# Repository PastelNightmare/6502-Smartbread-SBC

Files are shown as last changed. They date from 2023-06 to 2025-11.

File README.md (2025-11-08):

# Archiving, for now! I don't recommend using V1 of the board as of now.
As I play around with the finished PCB, I realized there are a few issues with it. 
- A13 is not connected to the RAM chip, so you have to make a jumper to it from elsewhere. 
- The below mentioned difference in clock generation from other processors to the WDC version.
- I'm using the WDC 65C22S, which does NOT have an open-drain interrupt output! It has a totem pole ouput! Right now, it's currently wired as if it were open drain, which is fine as long as you **don't use interrupts.** If you do though, you will short circuit the IRQ lines of the VIA.

# Upcoming hardware changes? 
- Reconnect A13, obviously.
- Make the system clock with WDC parts in mind
- Add schottky diodes on the VIA interrupts to connect them with the other open drain interrupts. Fine at 2mhz clock speed.
- Change address decoding to use Daryl Rictors DEC-1. https://sbc.rictor.org/decoder.html

# Upcoming software changes? 
- A customized version of EHBasic, which I've already made. Includes commands for sound, clearing screen, and returning to the monitor.
- Updating VGM player to load VGM out of RAM instead of ROM, and commented to explain better what it is doing. 
- Porting WozMon to this board for easier data entry. DeMon is fine, but it was more a project for me anyway. 
- A better terminal emulator program
- Eventually, using the new interrupts to allow streaming of VGM from the serial port. But that is a long time off. 

# IMPORTANT DESIGN NOTE
Due to a design difference with the WDC version of the 65C02 processor, this board will not work with WDC chips without a small modification. See "Using a WDC 65C02" below.

# SmartBread: A 6502 based single-board computer 
Its name came from a friend who called it this when they saw my initial prototypes on a breadboard. MintSpark Electronics was the working "maker name" for my projects, though it may not be for long. Other than another 6502 based single board computer, of which many exist, this was many firsts for me. Starting in 2017, I had a goal to build a 6502 system on a breadboard. As it grew, it became my first real endeavour into 6502 assembly, coding for an actual system, trying to make user friendly software, and PCB making. I now have working PCBs, a few programs, and much more work to do. 

Repo includes software, PCB gerber files and resources. ROM included has DeMon 4.0 and EhBASIC w/ its cold start monitor. Other files can be added and recompiled as desired 

Software assumes you are using the Kowalski 6502 simulator for assmebly. https://sbc.rictor.org/kowalski.html 

# Disclaimer: 
This was my first stab at assembly of any kind. While the code does exactly what I want it to do for this system, I understand that my code is not pretty by any stretch, and there is tons of room for improvement. I'm a novice, so please go easy on me. Some things like address decoding were figured out with the help of the 6502 forum and the 6502 Primer by Garth Wilson. Found at: http://wilsonminesco.com/

# Specs
- 65C02 processor running at 2mhz
- 2x 65C22 VIA (versatile interface adapter) chips
- 1x 65C51 ACIA (UART) chip
- SN76489 soundchip
- 32KB EEPROM (AT28C256)
- 16KB RAM (Alliance AS6C62256. 32kb chip, address decoding makes it 16kb)
- ATTINY26 for keyboard input
- Quad NAND gate 74 chip for address decoding
- Jumpers to fully configure serial port settings
- GPIO port, spare 8 bit parallel. 5v and GND also available. 
- PS2 keyboard input
- RCA output for sound. 
- Displays to charcter LCD or serial using any terminal device (board has a slot for the BatSocks tellymate tiny for this purpose http://www.batsocks.co.uk/products/Other/TellyMate%20Tiny.htm)

# Parts list
- R1-R6: 3.3k through hole resistor
- R7, R8: 10k through hole resistor
- R9: 370 ohm resistor. 
- C1: 1uf electrolytic capacitor. 
- All other capacitors: 100nf filter. Ceramic disc.
- 6502CLCK: ECS-100AX-018 oscillator, 2MHz
- SNCLCK: ECS-100AX-018 oscillator, 4MHz
- SERCLCK: ECS-100AX-018 oscillator, 1.8432MHz
- 65C02 processor
- VIA1, VIA2: 65C22 VIA chips (keyboard doesn't work right with non-CMOS versions)
- ACIA: 65C51 ACIA chip
- ROM: AT28C256
- RAM: Alliance AS6C62256
- ADDR: CD74HCT132E
- SN: Texas Instruments: SN76489
- ATTINY26: Atmel ATTINY26
- POWER: 5v through header, or surface mount USB Mini B jack. 

# Included Software
## DeMon 4.0
DeMon (DEvice MONitor) 4.0 is a basic memory monitor for the system. You can read the memory map, write to the memory map, run code, send commands directly to the sound chip, and much more. 
### Commands
All commands are processed by pressing enter. Accepts input from onboard PS2 keyboard or ACIA (with FTDI breakout)

| Command | Example | Description | 
| --- | --- | --- |
| Read  | 4000  | Displays data at address 0x4000  |
| List |L 2000.20FF| Will display all data between addresses 0x2000 and 0x20FF |
| Write  | W 2000 FF | Writes 0xFF at address 0x2000  |
| Write next | 00 | Data byte preceded with a space will write data to next location. MUST USE WRITE COMMAND FIRST |
| Run | R 2000 | Runs code starting at address 2000 | 
| Clear | CL | Clears all displays |
| Sound | S FF | Sends 0xFF to sound chip and makes the chip process it | 

## VGM player
A simple VGM player to play VGM files for the SN76489 sound chip. Expects raw VGM hex at 8900 (0900 if you're burning to ROM). Could easily be changed to load hex out of RAM instead with one line of code. 

## Enhanced 6502 BASIC 2.22 (EhBASIC) port
Made by Lee Davison, information: http://retro.hansotten.nl/6502-sbc/lee-davison-web-site/enhanced-6502-basic/. Ported to SmartBread by me. **COMPILING NOTE:** in order to compile EhBASIC, point the include line at the beginning of the Minimal Monitor to where you've downloaded EHBASIC.ASM. Minimal monitor starts at A000 and should be used to cold start BASIC! 

# Port Description
- GPIO - 8 bit parallel GPIO port. Can attach LCD to this port to work natively with DeMon, but it isn't required and can be used for whatever else the end user desires. The current board DOES NOT have the LCD enable line on this port, but it will be added to a future revision. 
- TM - Tellymate Tiny can be connected here for composite display. The part is discontinued, but eagle files and firmware exist on the Batsocks website. 
- Serial - Gives control lines for the ACIA ports, along with GNDs next to each one. Allows these status lines to be jumpered to ground, which **should** be done for most operations. (DTR, RTS, CTS, DCD) Also provides 5v and GND for user. Can connect to a TTL to RS232 converter for any type of serial display. 
- CLKMODE - Shorting these two pins with solder or a jumper allows the serial clock to also run the processor clock. This saves one part, but makes the CPU run slightly slower. 

# Using a WDC 65C02
In order to use a WDC version of the processor in the current revision, there is a slight modification to the board that must be made. Pin 39 (PHI2O) on the chip must be lifted out of the socket or removed. Then on the underside of the board, you must bridge a connection between Pin 39 and Pin 37 of the CPU socket. 

Traditionally, you provide the clock frequency to the CPU via PHI0/PHI2 input, then drive the rest of peripherals from PHI2O output from the CPU. The board was made with this in mind. WDC chips, however, do not test or guarantee the usability of the PHI2O output. They recommend that everything onboard receives its clock from the main oscillator driving the CPU. By bridging these two points on the board and lifting pin 39 from the chip, you are routing the clock in this manner. Future board revisions will have this as a jumper to ensure compatiblity. 

# To-do list / Wishlist 
- Update display to a new, non-discontinued solution. For now, Tellymate Tiny could be used, or provided serial pins can be attached to any device with a TTL to RS232 converter (Max232 and the like): Breakout USB boards, Converted RS232 port to a real glass terminal, etc. 
- Improve code by removing useless structures / subroutines
- Adding a binary load command to DeMon load binary data directly into memory from serial port. 
- Either standalone or built-in assembly evnironment for DeMon. 
- Text editor prorgram
- SPI protocol for various peripherals. 
- Cassette interface. 
- Rewrite my old code. The VGM player is old and hard to read. This was before I knew much about anything coding wise. 
- Write a terminal emulator program. I did make SimTerm originally, but it is hot garbage.

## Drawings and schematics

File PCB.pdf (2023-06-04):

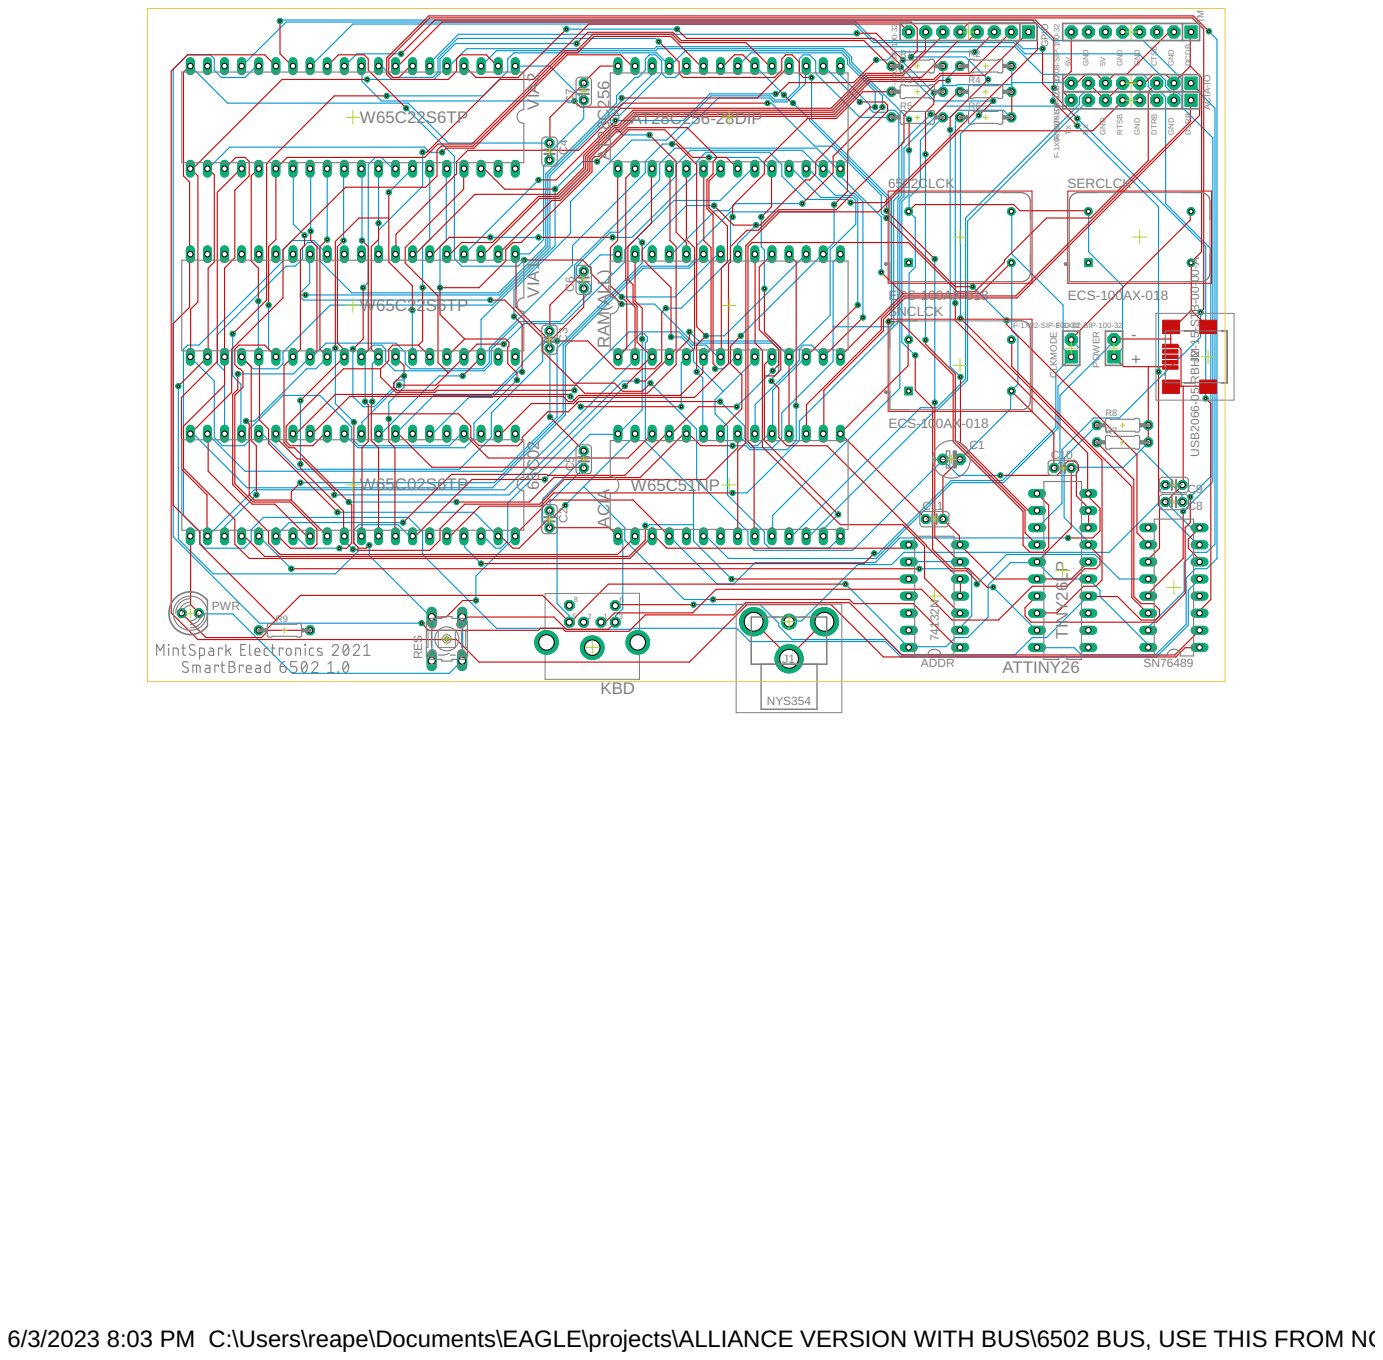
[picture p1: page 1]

6/3/2023 8:03 PM C:\Users\reape\Documents\EAGLE\projects\ALLIANCE VERSION WITH BUS\6502 BUS, USE THIS FROM NOW ON\6502 bus version\untitled.brd

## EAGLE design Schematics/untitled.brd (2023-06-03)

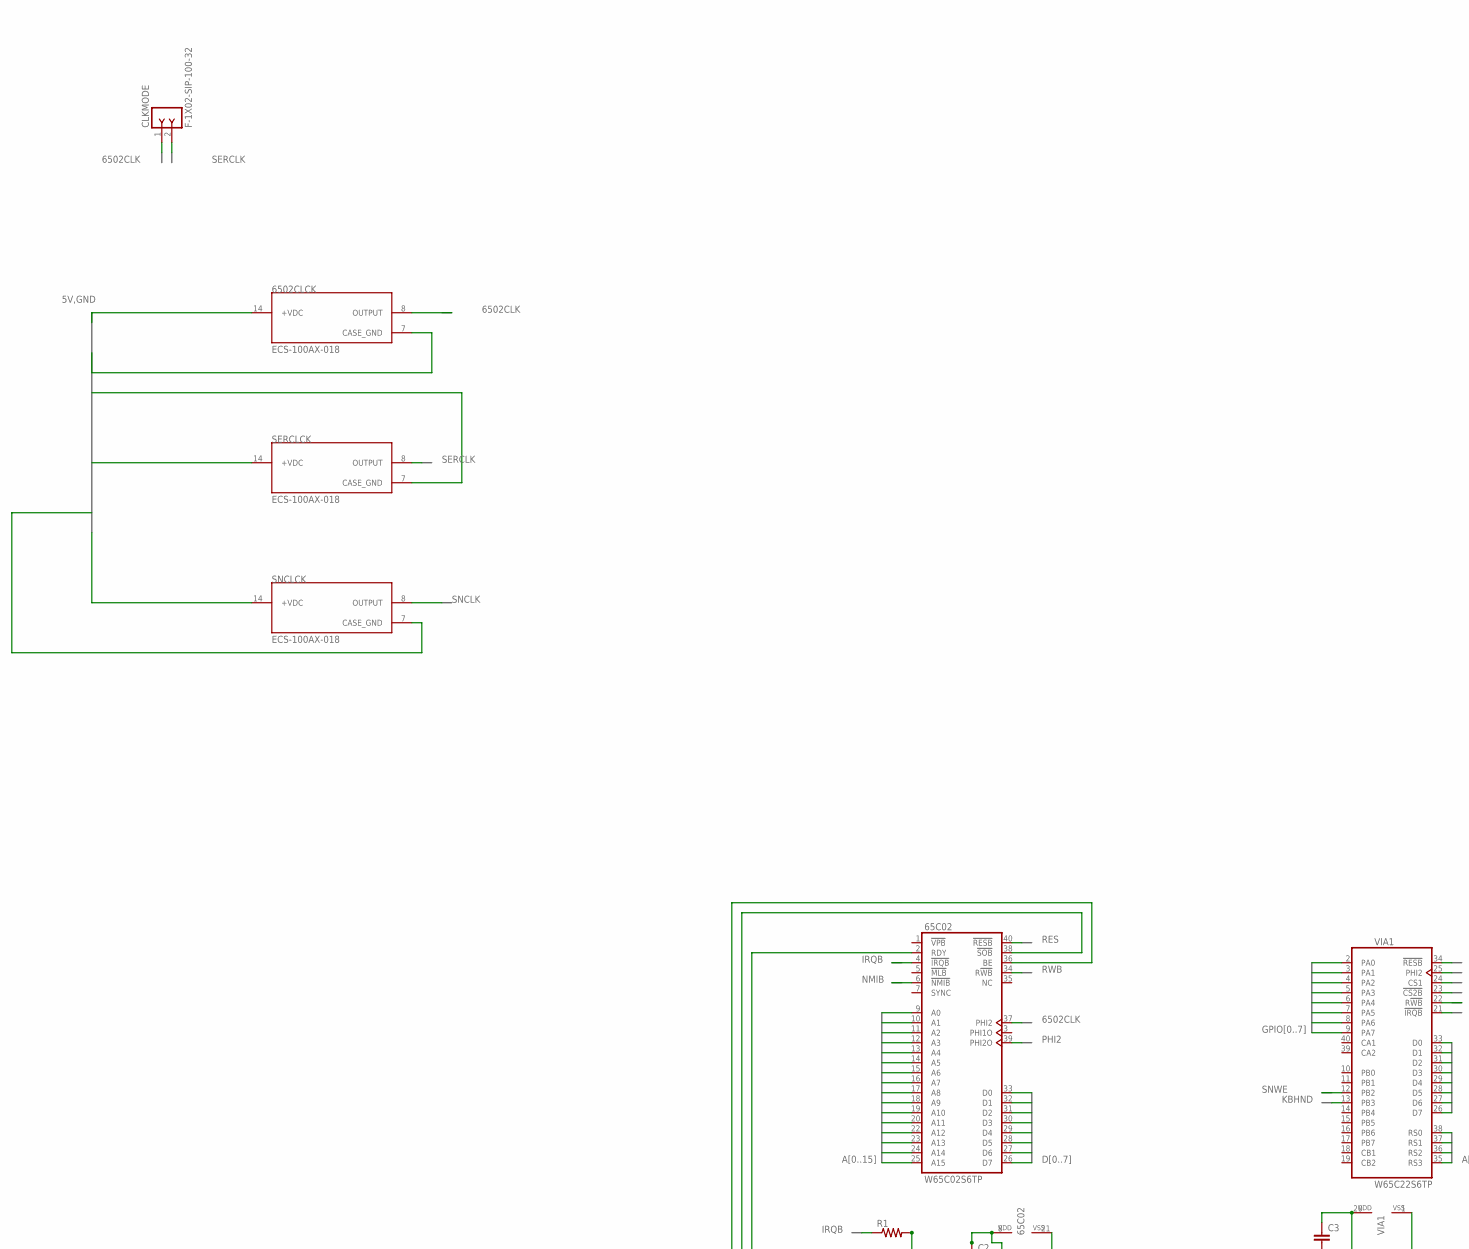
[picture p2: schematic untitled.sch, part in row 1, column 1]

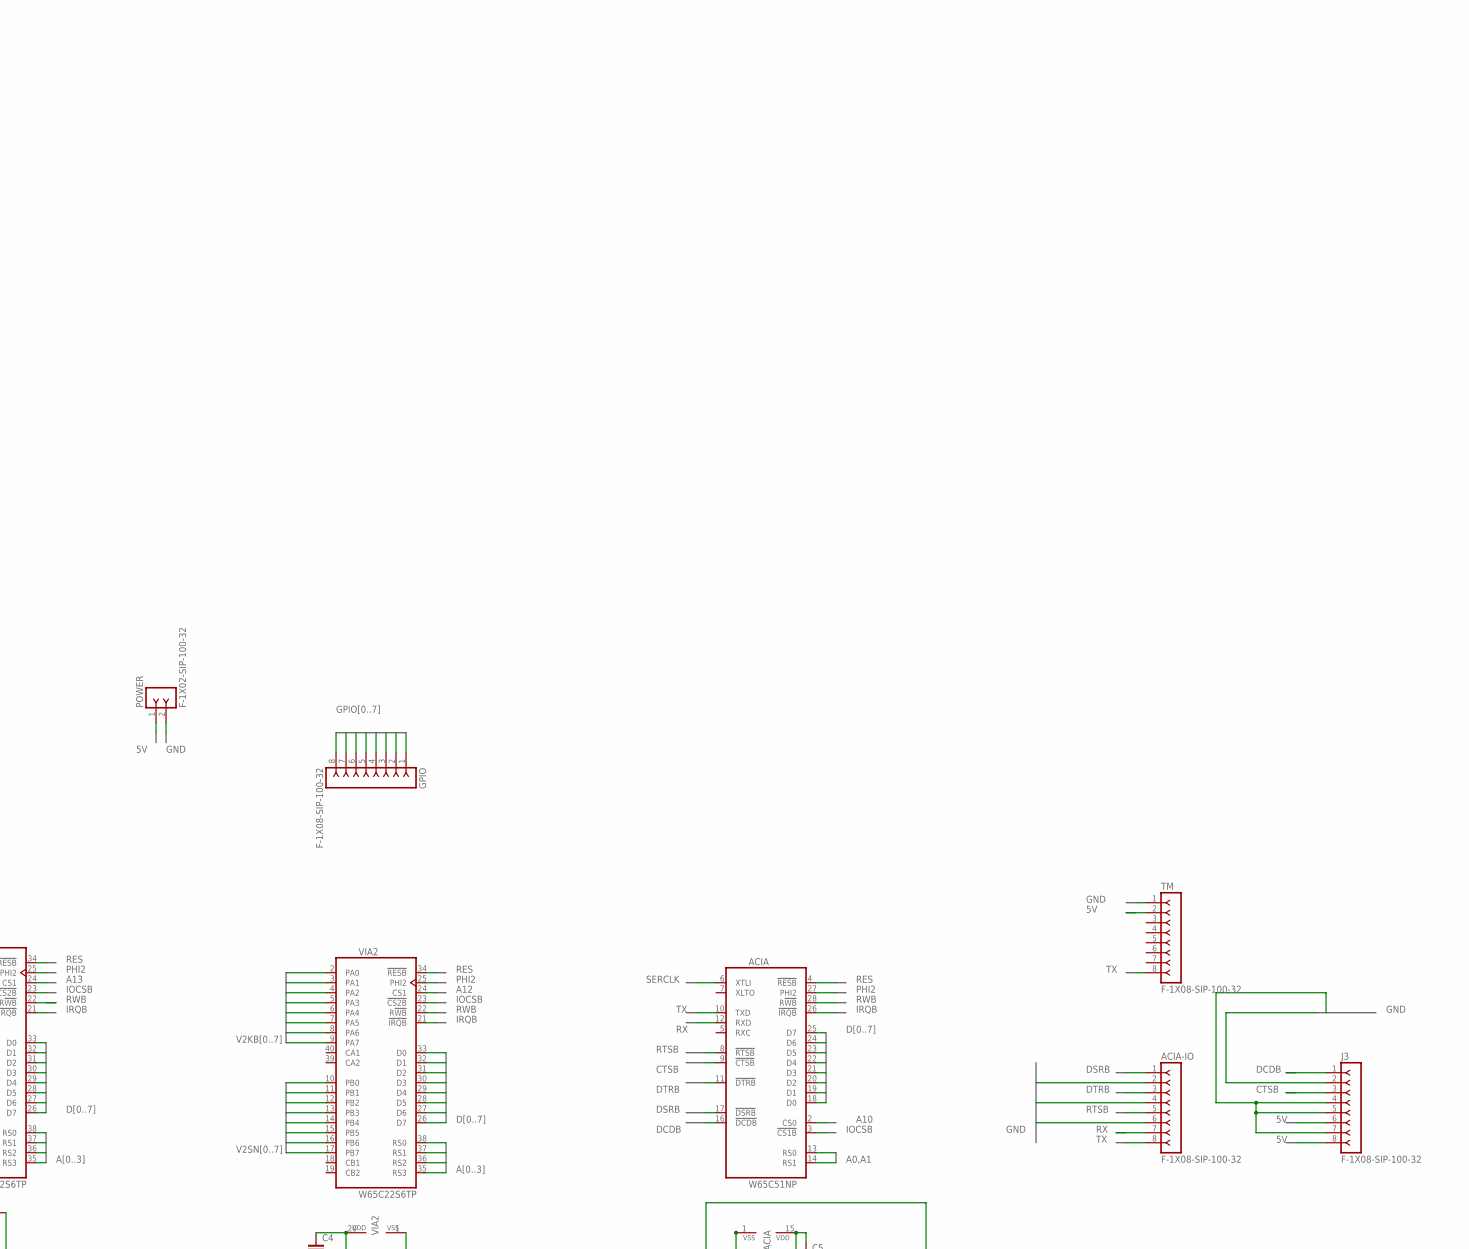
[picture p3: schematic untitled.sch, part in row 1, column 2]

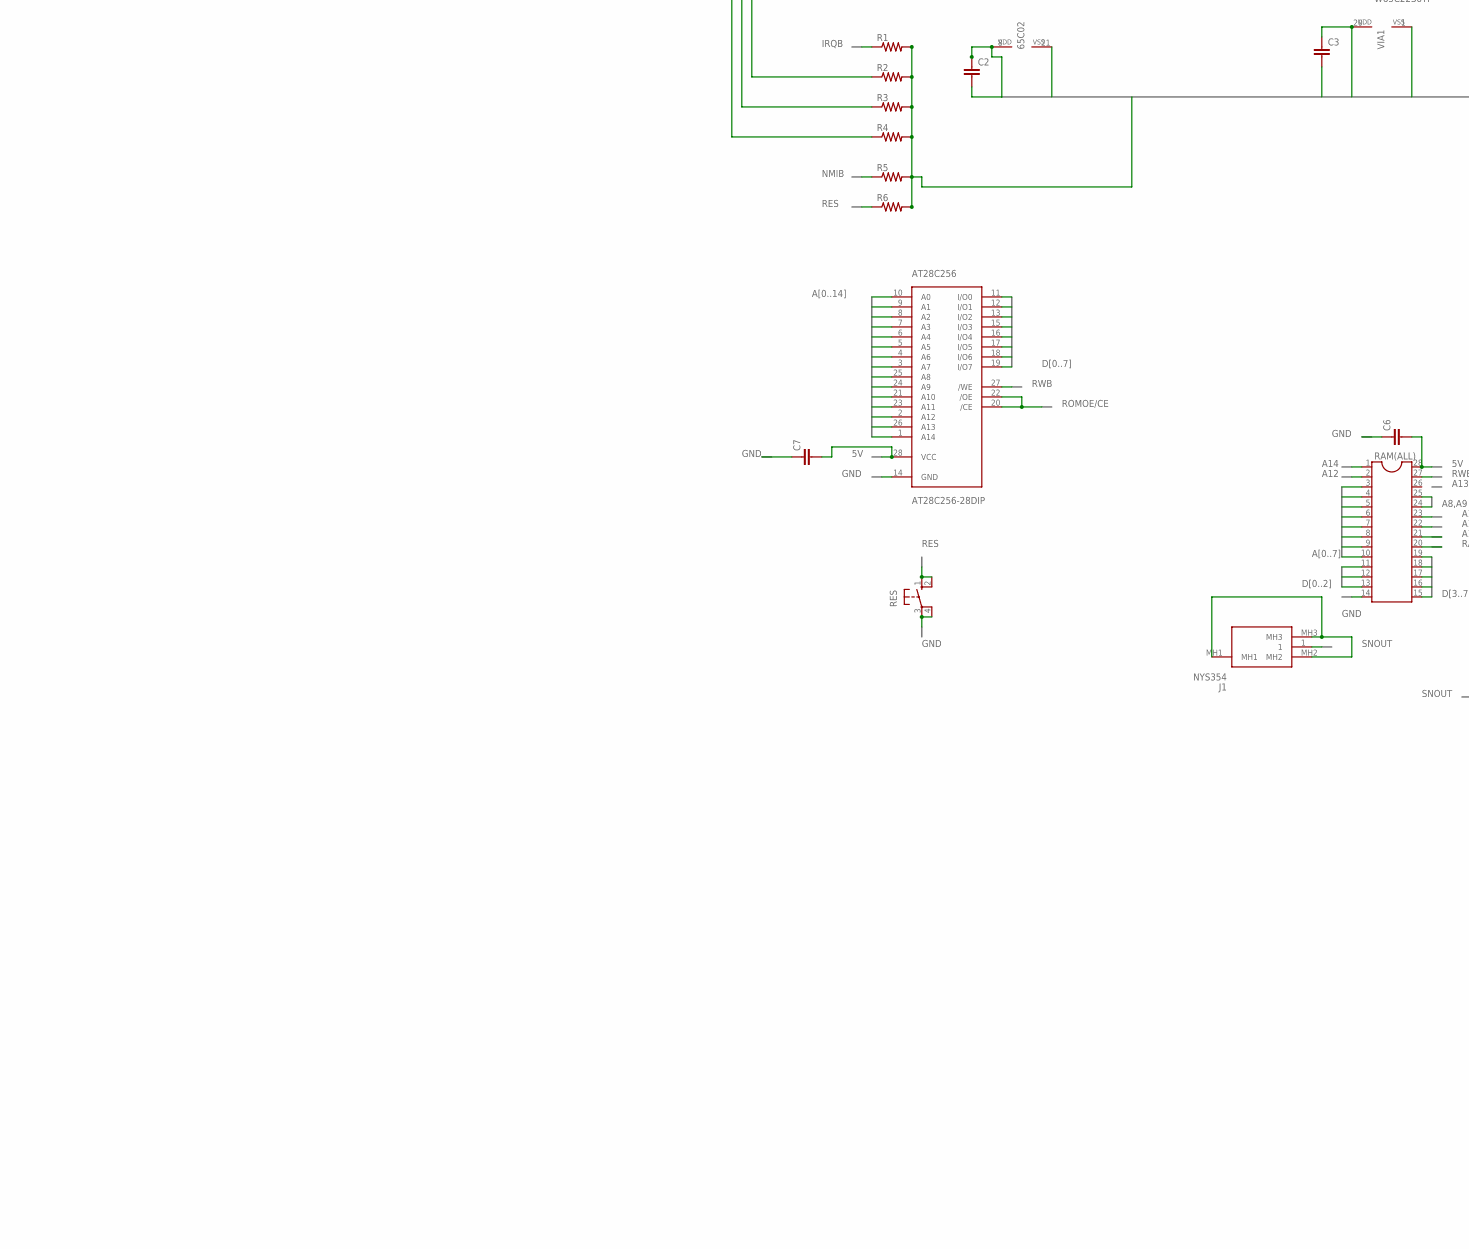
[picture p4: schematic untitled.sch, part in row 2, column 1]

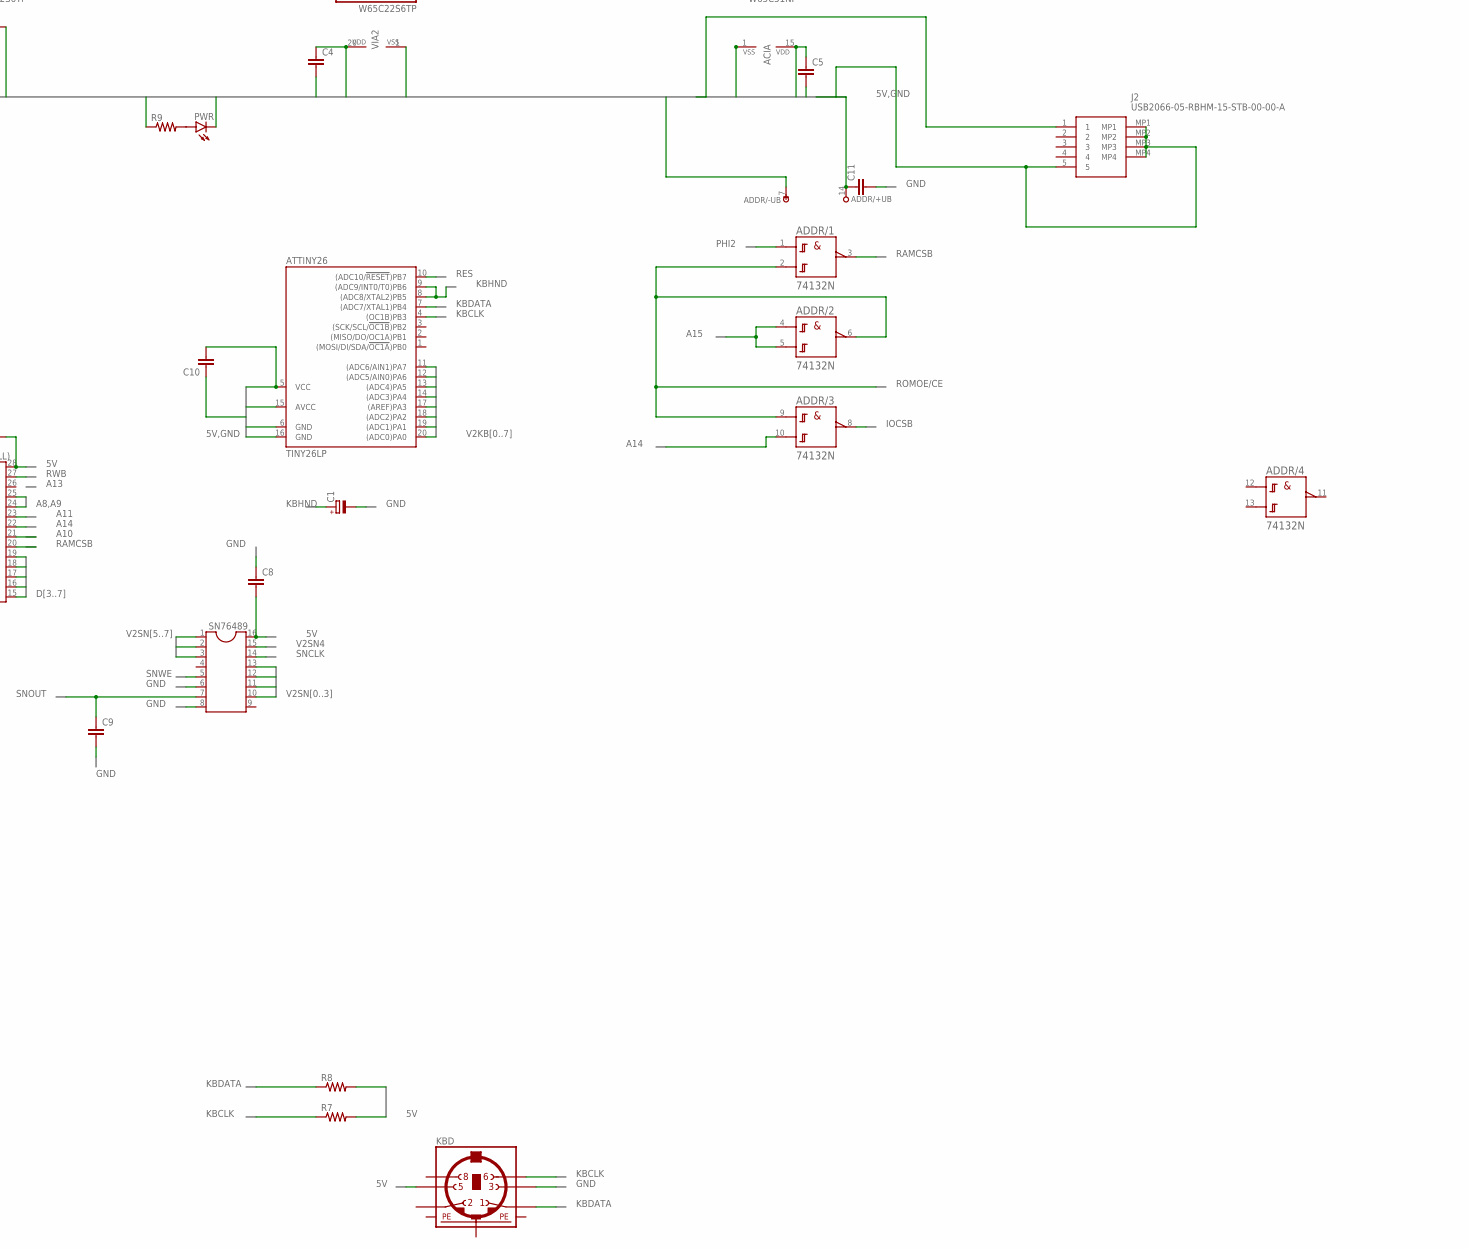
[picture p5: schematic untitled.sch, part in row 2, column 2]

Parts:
65C02: W65C02S6TP; DIL40
6502CLCK: ECS-100AX-018; OSC_ECS-100AX-018
ACIA: W65C51NP; DIL28-6
ACIA-IO: F-1X08-SIP-100-32; SIP-100-08-32
ADDR: 74132N; DIL14
AT28C256: AT28C256-28DIP; DIL28-6
ATTINY26: TINY26LP; DIL20
C1: CPOL-EUE2,5-6E; E2,5-6E
C2, C3, C4, C5, C6, C7, C8, C9, C10, C11: C-EU025-024X044; C025-024X044
CLKMODE: F-1X02-SIP-100-32; SIP-100-02-32
GPIO: F-1X08-SIP-100-32; SIP-100-08-32
J1: NYS354
J2: USB2066-05-RBHM-15-STB-00-00-A; USB206605RBHM15STB0000A
J3: F-1X08-SIP-100-32; SIP-100-08-32
KBD: MINI_DIN_6; M_DIN6
POWER: F-1X02-SIP-100-32; SIP-100-02-32
PWR: LED5MM
R1, R2, R3, R4, R5, R6, R7, R8, R9: R-US_0204/7; 0204/7
RAM(ALL): DIL28; DIL28-6
RES: 10-XX; B3F-10XX
SERCLCK: ECS-100AX-018; OSC_ECS-100AX-018
SN76489: DIL16
SNCLCK: ECS-100AX-018; OSC_ECS-100AX-018
TM: F-1X08-SIP-100-32; SIP-100-08-32
VIA1, VIA2: W65C22S6TP; DIL40

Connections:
5V: 65C02.8 (VDD), 6502CLCK.14 (+VDC), ACIA.15 (VDD), ADDR.14 (+UB), AT28C256.28 (VCC), ATTINY26.5 (VCC), ATTINY26.15 (AVCC), C2.1, C3.1, C4.1, C5.1, C6.2, C7.2, C8.2, C10.2, C11.1, J2.1, J3.6, J3.8, KBD.5, POWER.1, R1.2, R2.2, R3.2, R4.2, R5.2, R6.2, R7.2, R8.2, R9.1, RAM(ALL).28, SERCLCK.14 (+VDC), SN76489.16, SNCLCK.14 (+VDC), TM.2, VIA1.20 (VDD), VIA2.20 (VDD)
6502CLK: 65C02.37 (PHI2), 6502CLCK.8 (OUTPUT), CLKMODE.1
A0: 65C02.9 (A0), ACIA.13 (RS0), AT28C256.10 (A0), RAM(ALL).10, VIA1.38 (RS0), VIA2.38 (RS0)
A1: 65C02.10 (A1), ACIA.14 (RS1), AT28C256.9 (A1), RAM(ALL).9, VIA1.37 (RS1), VIA2.37 (RS1)
A2: 65C02.11 (A2), AT28C256.8 (A2), RAM(ALL).8, VIA1.36 (RS2), VIA2.36 (RS2)
A3: 65C02.12 (A3), AT28C256.7 (A3), RAM(ALL).7, VIA1.35 (RS3), VIA2.35 (RS3)
A4: 65C02.13 (A4), AT28C256.6 (A4), RAM(ALL).6
A5: 65C02.14 (A5), AT28C256.5 (A5), RAM(ALL).5
A6: 65C02.15 (A6), AT28C256.4 (A6), RAM(ALL).4
A7: 65C02.16 (A7), AT28C256.3 (A7), RAM(ALL).3
A8: 65C02.17 (A8), AT28C256.25 (A8), RAM(ALL).25
A9: 65C02.18 (A9), AT28C256.24 (A9), RAM(ALL).24
A10: 65C02.19 (A10), ACIA.2 (CS0), AT28C256.21 (A10), RAM(ALL).21
A11: 65C02.20 (A11), AT28C256.23 (A11), RAM(ALL).23
A12: 65C02.22 (A12), AT28C256.2 (A12), RAM(ALL).2, VIA2.24 (CS1)
A13: 65C02.23 (A13), AT28C256.26 (A13), VIA1.24 (CS1)
A14: 65C02.24 (A14), ADDR.10 (B), AT28C256.1 (A14), RAM(ALL).1, RAM(ALL).22
A15: 65C02.25 (A15), ADDR.4 (A), ADDR.5 (B)
CTSB: ACIA.9 (!CTSB), J3.3
D0: 65C02.33 (D0), ACIA.18 (D0), AT28C256.11 (I/O0), RAM(ALL).11, VIA1.33 (D0), VIA2.33 (D0)
D1: 65C02.32 (D1), ACIA.19 (D1), AT28C256.12 (I/O1), RAM(ALL).12, VIA1.32 (D1), VIA2.32 (D1)
D2: 65C02.31 (D2), ACIA.20 (D2), AT28C256.13 (I/O2), RAM(ALL).13, VIA1.31 (D2), VIA2.31 (D2)
D3: 65C02.30 (D3), ACIA.21 (D3), AT28C256.15 (I/O3), RAM(ALL).15, VIA1.30 (D3), VIA2.30 (D3)
D4: 65C02.29 (D4), ACIA.22 (D4), AT28C256.16 (I/O4), RAM(ALL).16, VIA1.29 (D4), VIA2.29 (D4)
D5: 65C02.28 (D5), ACIA.23 (D5), AT28C256.17 (I/O5), RAM(ALL).17, VIA1.28 (D5), VIA2.28 (D5)
D6: 65C02.27 (D6), ACIA.24 (D6), AT28C256.18 (I/O6), RAM(ALL).18, VIA1.27 (D6), VIA2.27 (D6)
D7: 65C02.26 (D7), ACIA.25 (D7), AT28C256.19 (I/O7), RAM(ALL).19, VIA1.26 (D7), VIA2.26 (D7)
DCDB: ACIA.16 (!DCDB), J3.1
DSRB: ACIA.17 (!DSRB), ACIA-IO.1
DTRB: ACIA.11 (!DTRB), ACIA-IO.3
GND: 65C02.21 (VSS), 6502CLCK.7 (CASE_GND), ACIA.1 (VSS), ACIA-IO.2, ACIA-IO.4, ACIA-IO.6, ADDR.7 (-UB), AT28C256.14 (GND), ATTINY26.6 (GND), ATTINY26.16 (GND), C1.-, C2.2, C3.2, C4.2, C5.2, C6.1, C7.1, C8.1, C9.2, C10.1, C11.2, J2.5, J2.MP1, J2.MP2, J2.MP3, J2.MP4, J3.2, J3.4, J3.5, J3.7, KBD.3, POWER.2, PWR.K (C), RAM(ALL).14, RES.3, RES.4 (P1), SERCLCK.7 (CASE_GND), SN76489.6, SN76489.8, SNCLCK.7 (CASE_GND), TM.1, VIA1.1 (VSS), VIA2.1 (VSS)
GPIO0: GPIO.1, VIA1.2 (PA0)
GPIO1: GPIO.2, VIA1.3 (PA1)
GPIO2: GPIO.3, VIA1.4 (PA2)
GPIO3: GPIO.4, VIA1.5 (PA3)
GPIO4: GPIO.5, VIA1.6 (PA4)
GPIO5: GPIO.6, VIA1.7 (PA5)
GPIO6: GPIO.7, VIA1.8 (PA6)
GPIO7: GPIO.8, VIA1.9 (PA7)
IOCSB: ACIA.3 (!CS1B), ADDR.8 (Y), VIA1.23 (!CS2B), VIA2.23 (!CS2B)
IRQB: 65C02.4 (!IRQB), ACIA.26 (!IRQB), R1.1, VIA1.21 (!IRQB), VIA2.21 (!IRQB)
KBCLK: ATTINY26.4 ((OC1B)PB3), KBD.6, R7.1
KBDATA: ATTINY26.7 ((ADC7/XTAL1)PB4), KBD.1, R8.1
KBHND: ATTINY26.8 ((ADC8/XTAL2)PB5), ATTINY26.9 ((ADC9/INT0/T0)PB6), C1.+, VIA1.13 (PB3)
unnamed: 65C02.36 (BE), R4.1
unnamed: PWR.A, R9.2
unnamed: 65C02.2 (RDY), R2.1
unnamed: 65C02.38 (!SOB), R3.1
unnamed: J1.MH1, J1.MH2, J1.MH3
NMIB: 65C02.6 (!NMIB), R5.1
PE1: KBD.SH1 (PE1)
PE2: KBD.SH2 (PE2)
PE3: KBD.SH3 (PE3)
PHI2: 65C02.39 (PHI2O), ACIA.27 (PHI2), ADDR.1 (A), VIA1.25 (PHI2), VIA2.25 (PHI2)
RAMCSB: ADDR.3 (Y), RAM(ALL).20
RES: 65C02.40 (!RESB), ACIA.4 (!RESB), ATTINY26.10 ((ADC10/!RESET!)PB7), R6.1, RES.1 (S), RES.2 (S1), VIA1.34 (!RESB), VIA2.34 (!RESB)
ROMOE/CE: ADDR.2 (B), ADDR.6 (Y), ADDR.9 (A), AT28C256.20 (/CE), AT28C256.22 (/OE)
RTSB: ACIA.8 (!RTSB), ACIA-IO.5
RWB: 65C02.34 (R!WB), ACIA.28 (R!WB), AT28C256.27 (/WE), RAM(ALL).27, VIA1.22 (R!WB), VIA2.22 (R!WB)
RX: ACIA.12 (RXD), ACIA-IO.7
SERCLK: ACIA.6 (XTLI), CLKMODE.2, SERCLCK.8 (OUTPUT)
SNCLK: SN76489.14, SNCLCK.8 (OUTPUT)
SNOUT: C9.1, J1.1, SN76489.7
SNWE: SN76489.5, VIA1.12 (PB2)
TX: ACIA.10 (TXD), ACIA-IO.8, TM.8
V2KB0: ATTINY26.20 ((ADC0)PA0), VIA2.2 (PA0)
V2KB1: ATTINY26.19 ((ADC1)PA1), VIA2.3 (PA1)
V2KB2: ATTINY26.18 ((ADC2)PA2), VIA2.4 (PA2)
V2KB3: ATTINY26.17 ((AREF)PA3), VIA2.5 (PA3)
V2KB4: ATTINY26.14 ((ADC3)PA4), VIA2.6 (PA4)
V2KB5: ATTINY26.13 ((ADC4)PA5), VIA2.7 (PA5)
V2KB6: ATTINY26.12 ((ADC5/AIN0)PA6), VIA2.8 (PA6)
V2KB7: ATTINY26.11 ((ADC6/AIN1)PA7), VIA2.9 (PA7)
V2SN0: SN76489.10, VIA2.10 (PB0)
V2SN1: SN76489.11, VIA2.11 (PB1)
V2SN2: SN76489.12, VIA2.12 (PB2)
V2SN3: SN76489.13, VIA2.13 (PB3)
V2SN4: SN76489.15, VIA2.14 (PB4)
V2SN5: SN76489.1, VIA2.15 (PB5)
V2SN6: SN76489.2, VIA2.16 (PB6)
V2SN7: SN76489.3, VIA2.17 (PB7)

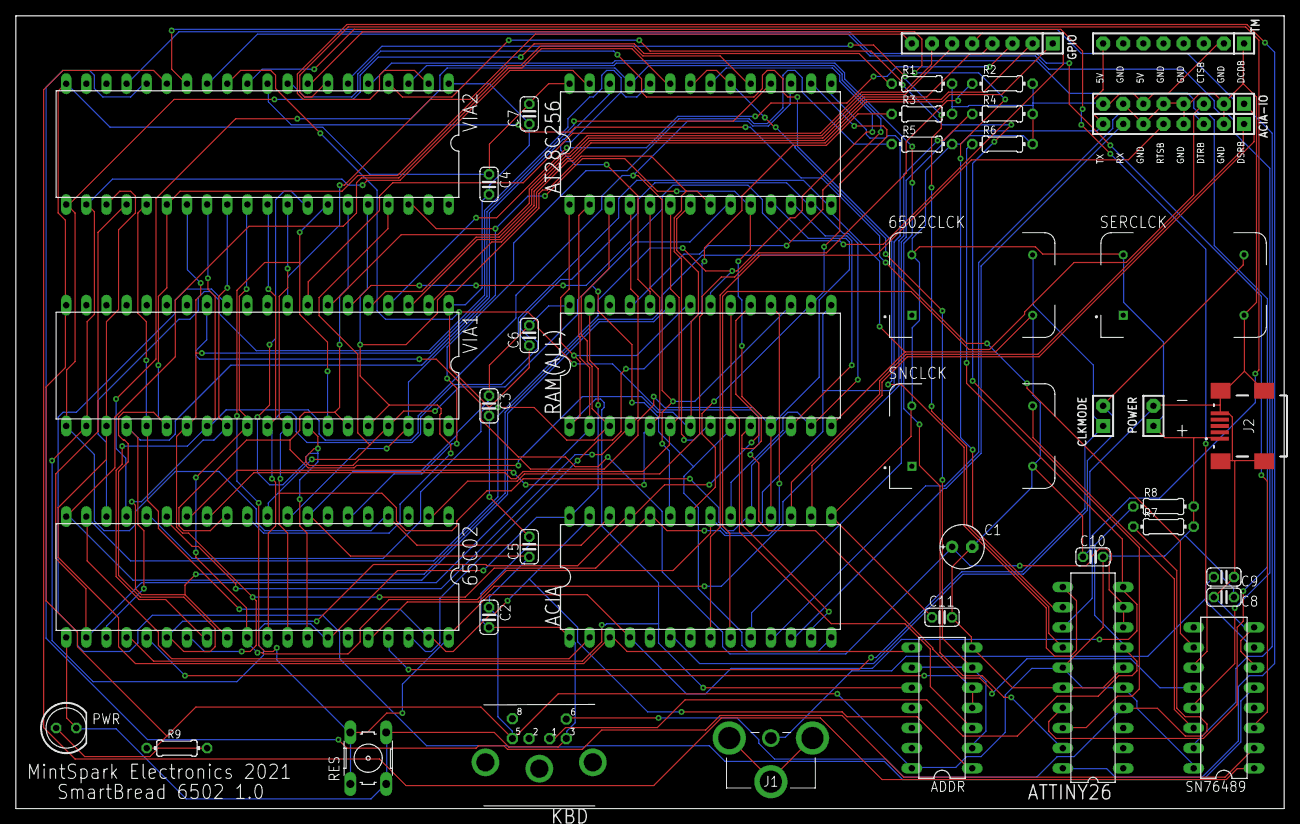
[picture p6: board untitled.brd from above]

Board: 2 copper layers, 160.0 x 100.0 mm, 43 parts (0 on the bottom side), 78 nets.

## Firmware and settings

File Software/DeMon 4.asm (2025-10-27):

; Device Monitor 2025 Dev Build
; Starting to refactor and fix jank
; Add conditional blocks to save space. If you're only using a serial port, you can disable LCD and Tellymate Tiny specifc code


LCDCONNECTED = 0 					; Set to 1 to tell assembler you're using LCD 
TMCONNECTED = 0 					; Set to 1 to tell assembler you're using tellymate tiny 

;Setting registers

VIAORA = $6001 						; VIA 1 output register A
VIADDRA = $6003 					; VIA 1 Port A data direction register 
VIAORB = $6000 						; VIA 1 output register B
VIADDRB = $6002 					; VIA 1 Port B data direction register

VI2ORA = $5001 						; Same order but starts with VIA 2 now.
VI2DDRA = $5003 				
VI2ORB = $5000  				
VI2DDRB = $5002 
VI2PCR = $500C 						; VIA 2 peripheral control register

ACIA_DATA = $4400					; ACIA registers. Named accordingly.
ACIA_STATUS = $4401
ACIA_COMMAND = $4402
ACIA_CONTROL = $4403

DROPCOUNT = $0050
 
 *=$0020 ; Zero page variables 
 
OUTPUT:  .DS $4 					; Buffer for converted Hex to Ascii. 
RESULT:  .DS $8						; Address of requested read location lives here. 
RESULT2: .DS $8 					; For list commands, the end of the address range we're searching for. 
WRITEV:  .DS $2 					; Data value converted FROM Ascii to Hex. Used for write commands.  
          
  *=$0800 						; Command-line input buffer
 
BUFFER: .RS $50

; ROM starts here. 
 
 *=$8000 

 
; Sets up and initializes all ICs / Peripherals. 

INITST: 
	
	LDX #$FF					
        TXS 						; Stack initialized
							; UART Initialized
UINIT:   
	 LDA #@00001011					; No parity, no echo, no interrupt
         STA ACIA_COMMAND
         LDA #@00011111					; 19200 8N1 connection
         STA ACIA_CONTROL
            


INITDDR: 
         LDA #$FF
         STA VIADDRA 					; VIA 1 Data Direction Register (DDR) A, all output. Character LCD data line / GPIO. Can rewrite as needed via DeMon	
         STA VI2DDRB 					; Via 1 DDR B all output. Sound chip data lines. 
         LDA #$00
         STA VI2DDRA 					; Via 2 DDRA all input. ASCII data from keyboard chip. 
         LDA #@11110111
         STA VIADDRB  					; Control signals, all output for LCD, sound chip. One input for keyboard handshaking. 
   
   .IF LCDCONNECTED       
	FLASHC: 						; LCD Initialization
        
 	        LDA #@00000110					; LCD Command Register, leaving enable line high. 
        	STA VIAORB 
         	LDA #$0F 
         	STA VIAORA 					; Turns on character LCD with blinking cursor
         	LDA #@00000100
         	STA VIAORB 
         	JSR DELAY					; Strobes enable line to tell LCD to process data, and delays to allow LCD to process command. 
	
	TWOLINE: 

         	LDA #@00000110 
         	STA VIAORB
         	LDA #@00111100
         	STA VIAORA 					; LCD using 8 data bits, 5x10 font, 2 lines. 
         	LDA #@00000100 
         	STA VIAORB
         	JSR DELAY					; Enable line strobe
         
	CLEAR: 
        	LDA #@00000110 
         	STA VIAORB
         	LDA #$01 					; Clear LCD
         	STA VIAORA
         	LDA #@00000100 
         	STA VIAORB
         	JSR DELAY					; Enable line strobe
         	LDA #@00000111
         	STA VIAORB					; Set VIA output register B to what it will need for the rest of monitor when not being used
 	.endif

						; Tellymate tiny (composite display terminal connected to ACIA) needs two dummy bits to initiate autobaud per manufacturer's spec. 
							; ASCII U (01010101) is recommended. Also sends commands to turn on autowrap, and clear the screen before printing splash message.
							; Per WDC instructions, new ACIA chips have a bug which breaks the TXE flag. You cannot check that to ensure data register is empty. 
							; Manufacturer recommends a delay after each bit data sent to it to ensure data register is ready for more data. So every serial 
    .if TMCONNECTED 					; related operation will have a delay as a result. First here, and then in the ECHO subroutine.   
               
	TELLYMATEINIT:
        	LDA #@01010101 
        	STA ACIA_DATA 
        	JSR DELAY					
        	STA ACIA_DATA 
        	JSR DELAY 					; Stores U on the ACIA data register twice
        	LDA #$1B 
        	STA ACIA_DATA
        	JSR DELAY
        	LDA #$76 					; Tellymate tiny commands are initiaed with ESC in ASCII and then another ASCII character to do a command. 76, autowrap on. 
        	STA ACIA_DATA
        	JSR DELAY
        	LDA #$1B
        	STA ACIA_DATA
        	JSR DELAY 
        	LDA #$45 					; 45. Clear screen
        	STA ACIA_DATA
        	JSR DELAY
  .endif  
       
                                   
MSGST: ; Mostly initalized. Let's make a splash message! 
     
        LDY #$00 					; Y register used as index for TEXT
GET:    LDA TEXT,Y 					; Loads character of text, indexed by Y. 
        BEQ SILENCE 					; End if we've reached $00, the end of our message
	JSR ECHO 					; Subroutine to place ACC on ACIA and LCD
        JSR DELAY  
        JSR DELAY 					; Delays needed for LCD, since I'm not reading from it to check busy flag. Lazy. 
        INY
        JMP GET 					; Moves the index to the next location, and loops to continue. 
        
        
TEXT: .BYTE "DeMon 4.1", $0A , $0D , $0A , $0D , "READY" , $0A, $0D, $0A, $0D, ">", $00
         

; Silences all channels of sound chip, sets tone data, and turns beep on and off. 

SILENCE: 	 					; VI2ORB is connected to sound chip data lines. PULSE strobes the enable line on SN to make it process data as command.
		 					; SN76489 documentation will cover how chip works. Not commenting much on what is going on here other than an overview. 
		 					; We send commands to silence each of the four channels, latch in tone data while silent to set the start beep to the 
		 					; pitch we want on channel 1, then briefly turn channel one on and back off. 
		 					
        LDA #@10111111 		
        STA VI2ORB
        JSR PULSE 
        LDA #@10011111 
        STA VI2ORB
        JSR PULSE
        LDA #@11011111 
        STA VI2ORB
        JSR PULSE
        LDA #$FF 
        STA VI2ORB 				
        JSR PULSE 

BEEP:		        
	LDA #@10001110
        STA VI2ORB
        JSR PULSE
      	LDA #@00001000 
      	STA VI2ORB
      	JSR PULSE
        LDA #@10010001 
        STA VI2ORB
      	JSR PULSE
      	JSR DELAYL 
      	LDA #@10011111 
      	STA VI2ORB
      	JSR PULSE
      	JMP PREP


              
; Warm start of monitor after all initialization and splash has been done. This is where the actual heart of the monitor code is
; General workflow is as follows: Take in data from keyboard or serial and place into a buffer. When enter is pressed, we check the first two characters to determine the desired command.
; We then parse data according to what command we're processing (figuring out an address to read or write from, a data byte to read or write, SN commands, etc)


PREP: ; 						; Y register is our index into the buffer

        LDY #$00
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

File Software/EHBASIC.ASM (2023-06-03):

VIAORA = $6001 ; VIA OUTPUT REGISTER A
VIADDRA = $6003 ; VIA DATA DIRECTION REGISTER A
VIAORB = $6000 ; VIA OUTPUT REGISTER B
VIADDRB = $6002 ; VIA DATA DIRECTION REGISTER B
VI2ORA = $5001 ; VIA 2 ORA
VI2DDRA = $5003 ; VIA 2 DDRA
VI2ORB = $5000 ; VIA 2 ORB
VI2DDRB = $5002 ; VIA 2 DDRB]
VI2PCR = $500C ; VIA2 HANDSHAKE
ACIA_DATA = $4400
ACIA_STATUS = $4401
ACIA_COMMAND = $4402
ACIA_CONTROL = $4403
; Enhanced BASIC to assemble under 6502 simulator, $ver 2.22

; $E7E1 $E7CF $E7C6 $E7D3 $E7D1 $E7D5 $E7CF $E81E $E825

; 2.00	new revision numbers start here
; 2.01	fixed LCASE$() and UCASE$()
; 2.02	new get value routine done
; 2.03	changed RND() to galoise method
; 2.04	fixed SPC()
; 2.05	new get value routine fixed
; 2.06	changed USR() code
; 2.07	fixed STR$()
; 2.08	changed INPUT and READ to remove need for $00 start to input buffer
; 2.09	fixed RND()
; 2.10	integrated missed changes from an earlier version
; 2.20	added ELSE to IF .. THEN and fixed IF .. GOTO <statement> to cause error
; 2.21	fixed IF .. THEN RETURN to not cause error
; 2.22	fixed RND() breaking the get byte routine

; zero page use ..

LAB_WARM 		= $00		; BASIC warm start entry point
Wrmjpl 		= LAB_WARM+1; BASIC warm start vector jump low byte
Wrmjph 		= LAB_WARM+2; BASIC warm start vector jump high byte

Usrjmp		= $0A		; USR function JMP address
Usrjpl		= Usrjmp+1	; USR function JMP vector low byte
Usrjph		= Usrjmp+2	; USR function JMP vector high byte
Nullct		= $0D		; nulls output after each line
TPos			= $0E		; BASIC terminal position byte
TWidth		= $0F		; BASIC terminal width byte
Iclim			= $10		; input column limit
Itempl		= $11		; temporary integer low byte
Itemph		= Itempl+1	; temporary integer high byte

nums_1		= Itempl	; number to bin/hex string convert MSB
nums_2		= nums_1+1	; number to bin/hex string convert
nums_3		= nums_1+2	; number to bin/hex string convert LSB

Srchc			= $5B		; search character
Temp3			= Srchc	; temp byte used in number routines
Scnquo		= $5C		; scan-between-quotes flag
Asrch			= Scnquo	; alt search character

XOAw_l		= Srchc	; eXclusive OR, OR and AND word low byte
XOAw_h		= Scnquo	; eXclusive OR, OR and AND word high byte

Ibptr			= $5D		; input buffer pointer
Dimcnt		= Ibptr	; # of dimensions
Tindx			= Ibptr	; token index

Defdim		= $5E		; default DIM flag
Dtypef		= $5F		; data type flag, $FF=string, $00=numeric
Oquote		= $60		; open quote flag (b7) (Flag: DATA scan; LIST quote; memory)
Gclctd		= $60		; garbage collected flag
Sufnxf		= $61		; subscript/FNX flag, 1xxx xxx = FN(0xxx xxx)
Imode			= $62		; input mode flag, $00=INPUT, $80=READ

Cflag			= $63		; comparison evaluation flag

TabSiz		= $64		; TAB step size (was input flag)

next_s		= $65		; next descriptor stack address

					; these two bytes form a word pointer to the item
					; currently on top of the descriptor stack
last_sl		= $66		; last descriptor stack address low byte
last_sh		= $67		; last descriptor stack address high byte (always $00)

des_sk		= $68		; descriptor stack start address (temp strings)

;			= $70		; End of descriptor stack

ut1_pl		= $71		; utility pointer 1 low byte
ut1_ph		= ut1_pl+1	; utility pointer 1 high byte
ut2_pl		= $73		; utility pointer 2 low byte
ut2_ph		= ut2_pl+1	; utility pointer 2 high byte

Temp_2		= ut1_pl	; temp byte for block move	

FACt_1		= $75		; FAC temp mantissa1
FACt_2		= FACt_1+1	; FAC temp mantissa2
FACt_3		= FACt_2+1	; FAC temp mantissa3

dims_l		= FACt_2	; array dimension size low byte
dims_h		= FACt_3	; array dimension size high byte

TempB			= $78		; temp page 0 byte

Smeml			= $79		; start of mem low byte		(Start-of-Basic)
Smemh			= Smeml+1	; start of mem high byte	(Start-of-Basic)
Svarl			= $7B		; start of vars low byte	(Start-of-Variables)
Svarh			= Svarl+1	; start of vars high byte	(Start-of-Variables)
Sarryl		= $7D		; var mem end low byte		(Start-of-Arrays)
Sarryh		= Sarryl+1	; var mem end high byte		(Start-of-Arrays)
Earryl		= $7F		; array mem end low byte	(End-of-Arrays)
Earryh		= Earryl+1	; array mem end high byte	(End-of-Arrays)
Sstorl		= $81		; string storage low byte	(String storage (moving down))
Sstorh		= Sstorl+1	; string storage high byte	(String storage (moving down))
Sutill		= $83		; string utility ptr low byte
Sutilh		= Sutill+1	; string utility ptr high byte
Ememl			= $85		; end of mem low byte		(Limit-of-memory)
Ememh			= Ememl+1	; end of mem high byte		(Limit-of-memory)
Clinel		= $87		; current line low byte		(Basic line number)
Clineh		= Clinel+1	; current line high byte	(Basic line number)
Blinel		= $89		; break line low byte		(Previous Basic line number)
Blineh		= Blinel+1	; break line high byte		(Previous Basic line number)

Cpntrl		= $8B		; continue pointer low byte
Cpntrh		= Cpntrl+1	; continue pointer high byte

Dlinel		= $8D		; current DATA line low byte
Dlineh		= Dlinel+1	; current DATA line high byte

Dptrl			= $8F		; DATA pointer low byte
Dptrh			= Dptrl+1	; DATA pointer high byte

Rdptrl		= $91		; read pointer low byte
Rdptrh		= Rdptrl+1	; read pointer high byte

Varnm1		= $93		; current var name 1st byte
Varnm2		= Varnm1+1	; current var name 2nd byte

Cvaral		= $95		; current var address low byte
Cvarah		= Cvaral+1	; current var address high byte

Frnxtl		= $97		; var pointer for FOR/NEXT low byte
Frnxth		= Frnxtl+1	; var pointer for FOR/NEXT high byte

Tidx1			= Frnxtl	; temp line index

Lvarpl		= Frnxtl	; let var pointer low byte
Lvarph		= Frnxth	; let var pointer high byte

prstk			= $99		; precedence stacked flag

comp_f		= $9B		; compare function flag, bits 0,1 and 2 used
					; bit 2 set if >
					; bit 1 set if =
					; bit 0 set if <

func_l		= $9C		; function pointer low byte
func_h		= func_l+1	; function pointer high byte

garb_l		= func_l	; garbage collection working pointer low byte
garb_h		= func_h	; garbage collection working pointer high byte

des_2l		= $9E		; string descriptor_2 pointer low byte
des_2h		= des_2l+1	; string descriptor_2 pointer high byte

g_step		= $A0		; garbage collect step size

Fnxjmp		= $A1		; jump vector for functions
Fnxjpl		= Fnxjmp+1	; functions jump vector low byte
Fnxjph		= Fnxjmp+2	; functions jump vector high byte

g_indx		= Fnxjpl	; garbage collect temp index

FAC2_r		= $A3		; FAC2 rounding byte

Adatal		= $A4		; array data pointer low byte
Adatah		= Adatal+1	; array data pointer high  byte

Nbendl		= Adatal	; new block end pointer low byte
Nbendh		= Adatah	; new block end pointer high  byte

Obendl		= $A6		; old block end pointer low byte
Obendh		= Obendl+1	; old block end pointer high  byte

numexp		= $A8		; string to float number exponent count
expcnt		= $A9		; string to float exponent count

numbit		= numexp	; bit count for array element calculations

numdpf		= $AA		; string to float decimal point flag
expneg		= $AB		; string to float eval exponent -ve flag

Astrtl		= numdpf	; array start pointer low byte
Astrth		= expneg	; array start pointer high  byte

Histrl		= numdpf	; highest string low byte
Histrh		= expneg	; highest string high  byte
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

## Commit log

2025-10-27 Space Saving Conditional Blocks
    Start of the first refactoring I'm doing. Allows user to set at run time if they'll be using a character LCD and Tellymate Tiny or not. If not, they won't be assembled. Saves space and enables GPIO port to be open for access.
    [DeMon 4.asm]
2025-11-08 Update README with archiving notes and future plans
    Added notes on hardware and software changes for the board.

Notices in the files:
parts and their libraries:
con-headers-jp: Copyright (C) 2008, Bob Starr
